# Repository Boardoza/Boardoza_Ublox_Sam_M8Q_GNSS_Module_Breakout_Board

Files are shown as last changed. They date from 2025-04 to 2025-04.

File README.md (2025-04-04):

# UBLOX SAM M8Q GNSS Module Breakout Board

The **Boardoza SAM-M8Q GNSS Breakout Module** is a **high-performance multi-GNSS receiver** designed for **precise positioning applications**. It integrates the **u-blox SAM-M8Q module**, which supports **GPS, GLONASS, and Galileo** satellite constellations for improved accuracy and reliability.  

This module operates with **3.3V or 5V**, making it compatible with a wide range of microcontrollers. It communicates with an MCU via **I<sup>2</sup>C and UART** interfaces, providing flexible integration for various applications, including **navigation systems, asset tracking, drones, and IoT-based geolocation solutions**.  

The **PPS, RST, INT, and SAFE** pins operate at **3.3V**, ensuring seamless interfacing with low-power microcontrollers.  

## [Click here to purchase!](https://www.ozdisan.com/maker-ve-iot-urunleri/boardoza/boardoza-modulleri/BOARDOZA-UBLOX/1206512)

|Front Side|Back Side|
|:---:|:---:|
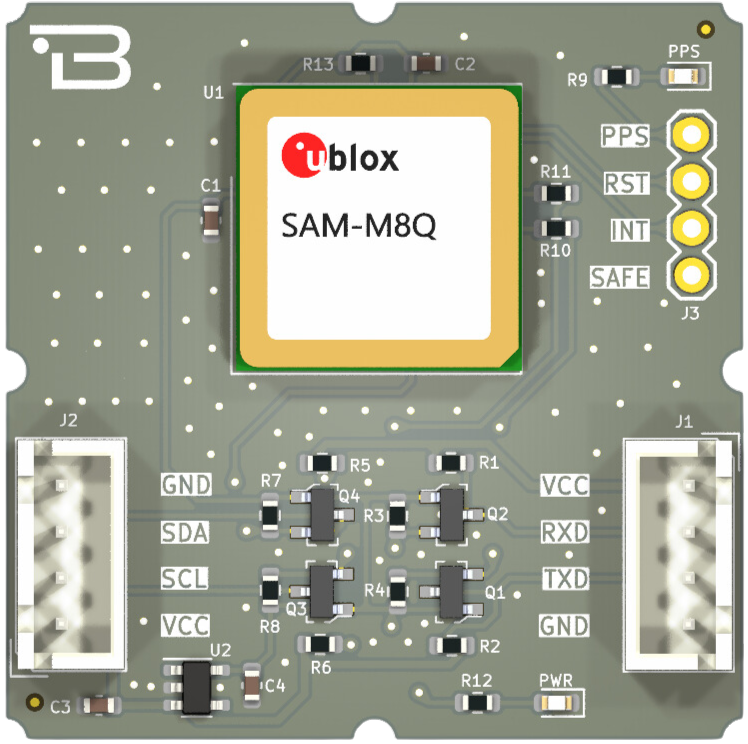
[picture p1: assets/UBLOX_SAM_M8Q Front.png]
Front
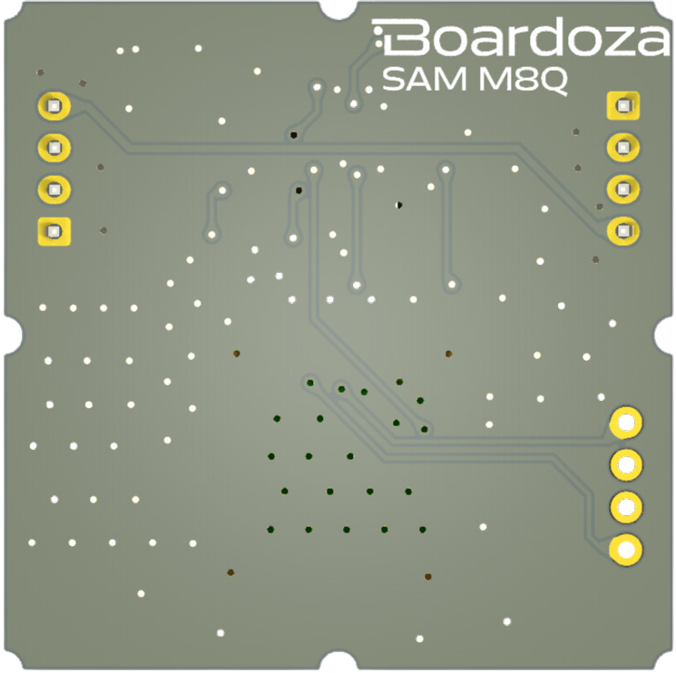
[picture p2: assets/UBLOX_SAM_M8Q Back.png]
Back
| | |

---

## Key Features

- **Multi-GNSS Support:** Compatible with GPS, GLONASS, and Galileo for enhanced positioning accuracy.  
- **Flexible Power Compatibility:** Operates with **3.3V or 5V**, making it suitable for a variety of MCUs.  
- **Dual Communication Interfaces:** Supports both **I<sup>2</sup>C and UART** for versatile connectivity.  
- **Time Pulse Output (PPS):** Provides precise timing synchronization at **1 pulse per second (default)**.  
- **Low Power Consumption:** Ideal for battery-operated applications such as **wearables and IoT tracking devices**.  
- **Industrial-Grade Performance:** Works reliably in extreme environments with a **temperature range of -40°C to +85°C**.  
- **Future-Proof Design:** Includes a **SAFEBOOT_N** function pin for firmware updates and configuration changes.  

---

## Technical Specifications

**Model:** u-blox SAM-M8Q  
**Input Voltage:** 3.3V - 5.5V  
**Voltage Input Type:** 4-pin 2.50mm header  
**Functions:** I<sup>2</sup>C and UART GNSS Receiver  
**Satellite Support:** GPS, GLONASS, Galileo, BeiDou  
**Time Pulse (PPS) Accuracy:** ±30 ns (typical)  
**Operating Temperature:** -40°C to +85°C  
**Board Dimensions:** 40mm x 40mm  

---

## Board Pinout

### **( J1 ) UART Communication Pins**  

| Pin Number | Pin Name | Description |
|:---:|:---:|---|
| 1 | GND | Ground |
| 2 | TXD | Transmitted Data Pin |
| 3 | RXD | Received Data Pin |
| 4 | VCC | Power Supply (3.3V - 5.5V) |

### **( J2 ) I<sup>2</sup>C Communication Pins**  

| Pin Number | Pin Name | Description |
|:---:|:---:|---|
| 1 | GND | Ground |
| 2 | SDA | I<sup>2</sup>C Serial Data Pin |
| 3 | SCL | I<sup>2</sup>C Serial Clock Pin |
| 4 | VCC | Power Supply (3.3V - 5.5V) |

### **( J3 ) Additional Function Pins**  

| Pin Number | Pin Name | Description |
|:---:|:---:|---|
| 1 | PPS | Time pulse signal (default: 1 pulse per second). See the u-blox M8 protocol specification for details. |
| 2 | RST | Active LOW reset pin. Internally pulled up to VCC. |
| 3 | INT | Used for time or frequency aiding data input to the receiver. |
| 4 | SAFE | SAFEBOOT_N function pin for firmware updates and reconfiguration (Reserved). |

---

## Board Dimensions

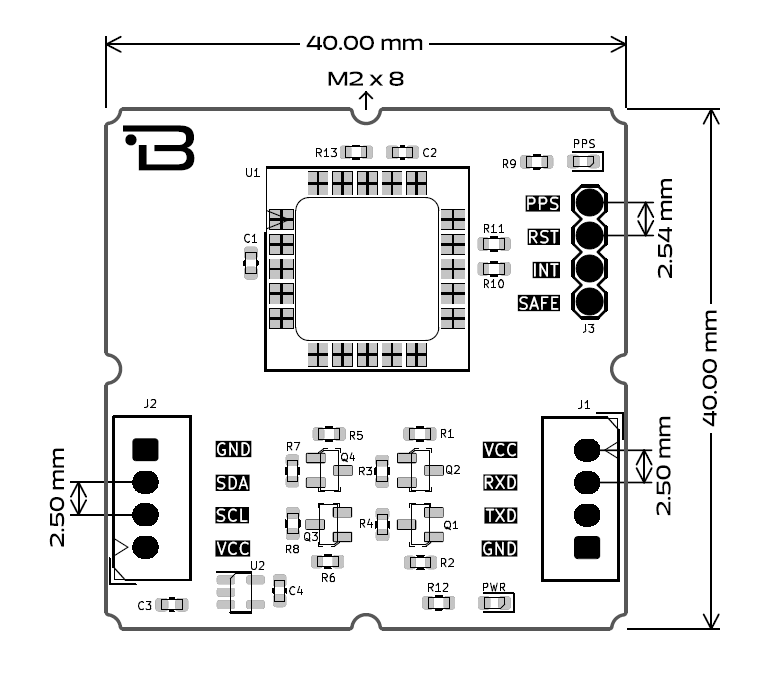
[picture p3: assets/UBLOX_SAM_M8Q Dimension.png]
Dimension


---

## Step Files

[Boardoza UBLOX SAM M8Q.step](./assets/UBLOX_SAM_M8Q%20Step.step)

---

## Datasheet

[Boardoza UBLOX SAM M8Q Datasheet.pdf](./assets/UBLOX_SAM_M8Q%20Datasheet.pdf)

---

## Version History

- V1.0.0 - Initial Release

---

## Support

- If you have any questions or need support, please contact <support@boardoza.com>

---

## License

Shield: [][cc-by-sa]

This work is licensed under a [Creative Commons Attribution-ShareAlike 4.0 International License][cc-by-sa].

[][cc-by-sa]

[cc-by-sa]: http://creativecommons.org/licenses/by-sa/4.0/
[cc-by-sa-image]: https://licensebuttons.net/l/by-sa/4.0/88x31.png
[cc-by-sa-shield]: https://img.shields.io/badge/License-CC%20BY--SA%204.0-lightgrey.svg

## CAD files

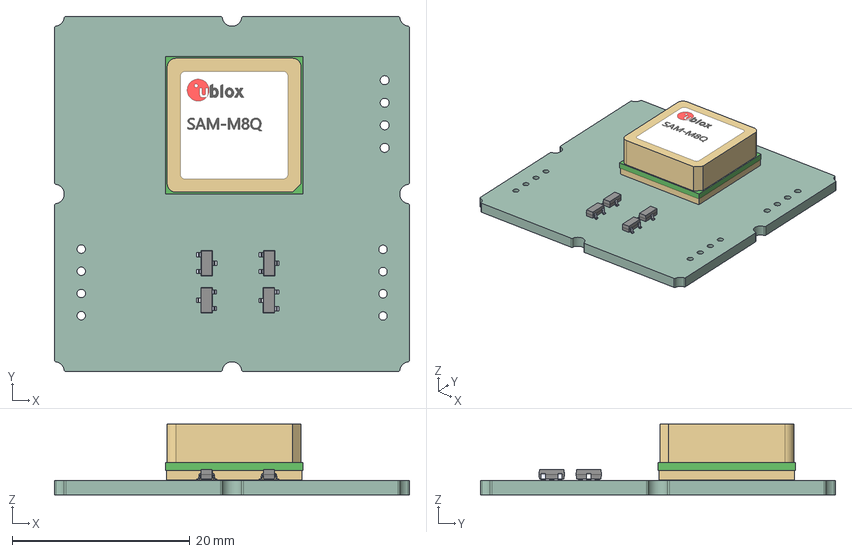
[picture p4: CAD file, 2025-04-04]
assets/UBLOX_SAM_M8Q Step.step
40.0 x 40.0 x 7.95 mm
MAX6103EUR-T x 4
sam-mq8
_autosave-B-UBLOX_SAM_M8Q-Brk-01Mbr-R01_PCB

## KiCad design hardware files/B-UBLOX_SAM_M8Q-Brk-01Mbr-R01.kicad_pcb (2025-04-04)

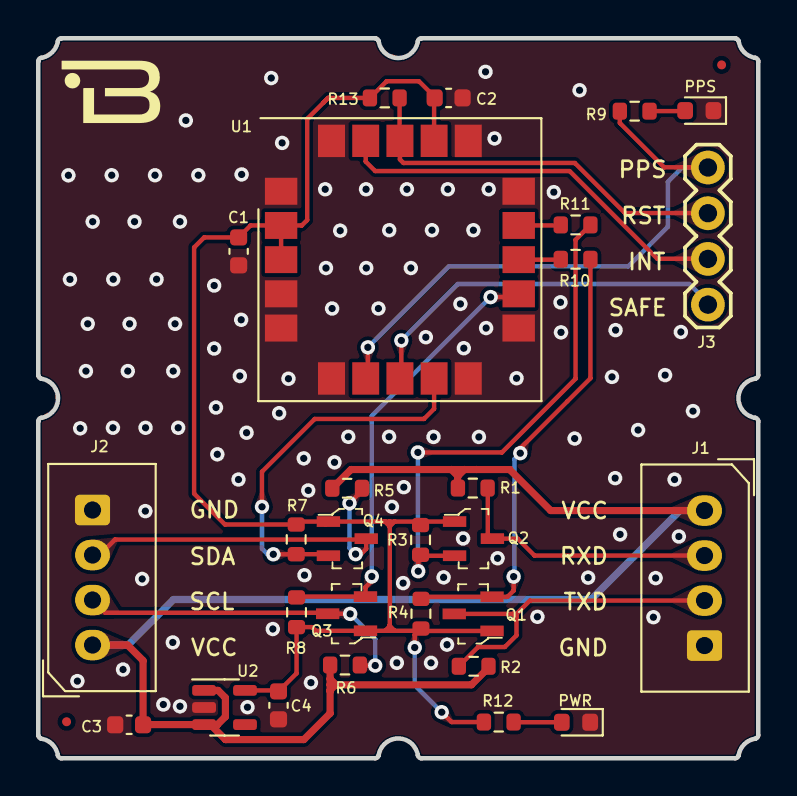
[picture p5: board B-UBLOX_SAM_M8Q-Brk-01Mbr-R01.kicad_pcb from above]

Board: 2 copper layers, 40.0 x 40.0 mm, 28 parts (0 on the bottom side), 19 nets.

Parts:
C1, C2: 100nF; C_0603_1608Metric
C3, C4: 1uF; C_0603_1608Metric
J1, J2: MOLEX_CONNECTOR_1X4; 2317-04S_1x04_P2.50mm_Vertical
J3: CONN_04; 1X04
PPS: LED RED; LED_0603_1608Metric
PWR: LED POWER; LED_0603_1608Metric
Q1, Q2, Q3, Q4: 2N7002_R1_00001; SOT-23-3
R1, R2, R3, R4, R5, R6, R7, R8, R9, R12, R13: 10K; R_0603_1608Metric
R10, R11: 470; R_0603_1608Metric
U1: ublox_SAM-M8Q
U2: TLV73333PDBVR; SOT-23-5

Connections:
+3V3: C1.1, C2.1, C4.1, Q1.1 (G), Q2.1 (G), Q3.1 (G), Q4.1 (G), R3.1, R4.1, R7.1, R8.1, R12.1, R13.2, U1.2 (VCC_IO), U1.3 (V_BCKP), U1.17 (VCC), U2.5 (OUT)
GND: C1.2, C2.2, C3.2, C4.2, J1.4, J2.4, PPS.1 (K), PWR.1 (K), U1.1 (GND), U1.4 (GND), U1.5 (GND), U1.6 (GND), U1.10 (GND), U1.11 (GND), U1.15 (GND), U1.16 (GND), U1.20 (GND), U2.2 (GND)
GPS_INT: J3.3, U1.19 (EXTINT)
GPS_RX: R11.2, U1.14 (RXD)
GPS_SCL: Q3.2 (S), R8.2, U1.12 (SCL)
GPS_SDA: Q4.2 (S), R7.2, U1.9 (SDA)
GPS_TX: R10.2, U1.13 (TXD)
unnamed: PPS.2 (A), R9.2
unnamed: PWR.2 (A), R12.2
unnamed: Q1.2 (S), R4.2, R10.1
unnamed: Q2.2 (S), R3.2, R11.1
PPS: J3.1, R9.1, U1.7 (TIMEPULSE)
RESET: J3.2, R13.1, U1.18 (~RESET)
RXD: J1.2, Q2.3 (D), R1.2
SAFEBOOT: J3.4, U1.8 (~SAFEBOOT)
SCL: J2.2, Q3.3 (D), R6.2
SDA: J2.3, Q4.3 (D), R5.2
TXD: J1.3, Q1.3 (D), R2.2
VCC: C3.1, J1.1, J2.1, R1.1, R2.1, R5.1, R6.1, U2.1 (IN), U2.3 (EN)

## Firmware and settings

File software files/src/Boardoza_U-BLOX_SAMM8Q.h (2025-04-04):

/*
  This is a library written for the u-blox ZED-F9P and NEO-M8P-2
  Boardoza sells these at its website: www.sparkfun.com
  Do you like this library? Help support SparkFun. Buy a board!
  https://www.sparkfun.com/products/16481
  https://www.sparkfun.com/products/15136
  https://www.sparkfun.com/products/15005
  https://www.sparkfun.com/products/15733
  https://www.sparkfun.com/products/15193
  https://www.sparkfun.com/products/15210

  Original version by Nathan Seidle @ SparkFun Electronics, September 6th, 2018
  v2.0 rework by Paul Clark @ SparkFun Electronics, December 31st, 2020

  This library handles configuring and handling the responses
  from a u-blox GPS module. Works with most modules from u-blox including
  the Zed-F9P, NEO-M8P-2, NEO-M9N, ZOE-M8Q, SAM-M8Q, and many others.

  https://github.com/sparkfun/SparkFun_Ublox_Arduino_Library

  Development environment specifics:
  Arduino IDE 1.8.13

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
  THE SOFTWARE IS PROVIDED "AS IS", WITHOUT WARRANTY OF ANY KIND, EXPRESS OR IMPLIED, INCLUDING BUT
  NOT LIMITED TO THE WARRANTIES OF MERCHANTABILITY, FITNESS FOR A PARTICULAR PURPOSE AND NONINFRINGEMENT.
  IN NO EVENT SHALL THE AUTHORS OR COPYRIGHT HOLDERS BE LIABLE FOR ANY CLAIM, DAMAGES OR OTHER LIABILITY,
  WHETHER IN AN ACTION OF CONTRACT, TORT OR OTHERWISE, ARISING FROM, OUT OF OR IN CONNECTION WITH THE
  SOFTWARE OR THE USE OR OTHER DEALINGS IN THE SOFTWARE.
*/

#ifndef BOARDOZA_UBLOX_SAMM8Q_H
#define BOARDOZA_UBLOX_SAMM8Q_H

#if (ARDUINO >= 100)
#include "Arduino.h"
#else
#include "WProgram.h"
#endif

#include <Wire.h>

#include <SPI.h>

#include "u-blox_config_keys.h"
#include "u-blox_structs.h"

// Uncomment the next line (or add SFE_UBLOX_REDUCED_PROG_MEM as a compiler directive) to reduce the amount of program memory used by the library
//#define SFE_UBLOX_REDUCED_PROG_MEM // Uncommenting this line will delete the minor debug messages to save memory

// Uncomment the next line (or add SFE_UBLOX_DISABLE_AUTO_NMEA as a compiler directive) to reduce the amount of program memory used by the library
//#define SFE_UBLOX_DISABLE_AUTO_NMEA // Uncommenting this line will disable auto-NMEA support to save memory

// The code exceeds the program memory on the ATmega328P (Arduino Uno), so let's delete the minor debug messages and disable auto-NMEA support anyway
// However, the ATmega2560 and ATmega1280 _do_ have enough memory, so let's exclude those
#if !defined(SFE_UBLOX_REDUCED_PROG_MEM) && defined(ARDUINO_ARCH_AVR) && !defined(ARDUINO_AVR_MEGA2560) && !defined(ARDUINO_AVR_MEGA) && !defined(ARDUINO_AVR_ADK)
#define SFE_UBLOX_REDUCED_PROG_MEM
#endif
#if !defined(SFE_UBLOX_DISABLE_AUTO_NMEA) && defined(ARDUINO_ARCH_AVR) && !defined(ARDUINO_AVR_MEGA2560) && !defined(ARDUINO_AVR_MEGA) && !defined(ARDUINO_AVR_ADK)
#define SFE_UBLOX_DISABLE_AUTO_NMEA
#endif

//-=-=-=-=-=-=-=-=-=-=-=-=-=-=-=-=-=-=-=-=-=-=-=-=-=-=-=-=-=-=-=-=-=-=-=-=

// Define a digital pin to aid debugging
// Leave set to -1 if not needed
const int debugPin = -1;

// Global Status Returns
typedef enum
{
  SFE_UBLOX_STATUS_SUCCESS,
  SFE_UBLOX_STATUS_FAIL,
  SFE_UBLOX_STATUS_CRC_FAIL,
  SFE_UBLOX_STATUS_TIMEOUT,
  SFE_UBLOX_STATUS_COMMAND_NACK, // Indicates that the command was unrecognised, invalid or that the module is too busy to respond
  SFE_UBLOX_STATUS_OUT_OF_RANGE,
  SFE_UBLOX_STATUS_INVALID_ARG,
  SFE_UBLOX_STATUS_INVALID_OPERATION,
  SFE_UBLOX_STATUS_MEM_ERR,
  SFE_UBLOX_STATUS_HW_ERR,
  SFE_UBLOX_STATUS_DATA_SENT,     // This indicates that a 'set' was successful
  SFE_UBLOX_STATUS_DATA_RECEIVED, // This indicates that a 'get' (poll) was successful
  SFE_UBLOX_STATUS_I2C_COMM_FAILURE,
  SFE_UBLOX_STATUS_DATA_OVERWRITTEN // This is an error - the data was valid but has been or _is being_ overwritten by another packet
} sfe_ublox_status_e;

// ubxPacket validity
typedef enum
{
  SFE_UBLOX_PACKET_VALIDITY_NOT_VALID,
  SFE_UBLOX_PACKET_VALIDITY_VALID,
  SFE_UBLOX_PACKET_VALIDITY_NOT_DEFINED,
  SFE_UBLOX_PACKET_NOTACKNOWLEDGED // This indicates that we received a NACK
} sfe_ublox_packet_validity_e;

// Identify which packet buffer is in use:
// packetCfg (or a custom packet), packetAck or packetBuf
// packetAuto is used to store expected "automatic" messages
typedef enum
{
  SFE_UBLOX_PACKET_PACKETCFG,
  SFE_UBLOX_PACKET_PACKETACK,
  SFE_UBLOX_PACKET_PACKETBUF,
  SFE_UBLOX_PACKET_PACKETAUTO
} sfe_ublox_packet_buffer_e;
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

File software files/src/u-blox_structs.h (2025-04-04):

/*
  This is a library written for the u-blox ZED-F9P and NEO-M8P-2
  SparkFun sells these at its website: www.sparkfun.com
  Do you like this library? Help support SparkFun. Buy a board!
  https://www.sparkfun.com/products/16481
  https://www.sparkfun.com/products/15136
  https://www.sparkfun.com/products/15005
  https://www.sparkfun.com/products/15733
  https://www.sparkfun.com/products/15193
  https://www.sparkfun.com/products/15210

  Original version by Nathan Seidle @ SparkFun Electronics, September 6th, 2018
  v2.0 rework by Paul Clark @ SparkFun Electronics, December 31st, 2020

  This library handles configuring and handling the responses
  from a u-blox GPS module. Works with most modules from u-blox including
  the Zed-F9P, NEO-M8P-2, NEO-M9N, ZOE-M8Q, SAM-M8Q, and many others.

  https://github.com/sparkfun/SparkFun_Ublox_Arduino_Library

  Development environment specifics:
  Arduino IDE 1.8.13

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
  THE SOFTWARE IS PROVIDED "AS IS", WITHOUT WARRANTY OF ANY KIND, EXPRESS OR IMPLIED, INCLUDING BUT
  NOT LIMITED TO THE WARRANTIES OF MERCHANTABILITY, FITNESS FOR A PARTICULAR PURPOSE AND NONINFRINGEMENT.
  IN NO EVENT SHALL THE AUTHORS OR COPYRIGHT HOLDERS BE LIABLE FOR ANY CLAIM, DAMAGES OR OTHER LIABILITY,
  WHETHER IN AN ACTION OF CONTRACT, TORT OR OTHERWISE, ARISING FROM, OUT OF OR IN CONNECTION WITH THE
  SOFTWARE OR THE USE OR OTHER DEALINGS IN THE SOFTWARE.
*/

#ifndef __u_blox_structs_h__
#define __u_blox_structs_h__

#include "Boardoza_U-BLOX_SAMM8Q.h"

#ifndef DEF_NUM_SENS
#define DEF_NUM_SENS 7 // The maximum number of ESF sensors
#endif

#ifndef DEF_MAX_NUM_ESF_RAW_REPEATS
#define DEF_MAX_NUM_ESF_RAW_REPEATS 10 // The NEO-M8U sends ESF RAW data in blocks / sets of ten readings. (The ZED-F9R sends them one at a time.)
#endif

#ifndef DEF_MAX_NUM_ESF_MEAS
#define DEF_MAX_NUM_ESF_MEAS 31 // numMeas is 5 bits, indicating up to 31 groups could be received
#endif

// Additional flags and pointers that need to be stored with each message type
struct ubxAutomaticFlags
{
  union
  {
    uint8_t all;
    struct
    {
      uint8_t automatic : 1;         // Will this message be delivered and parsed "automatically" (without polling)
      uint8_t implicitUpdate : 1;    // Is the update triggered by accessing stale data (=true) or by a call to checkUblox (=false)
      uint8_t addToFileBuffer : 1;   // Should the raw UBX data be added to the file buffer?
      uint8_t callbackCopyValid : 1; // Is the copy of the data struct used by the callback valid/fresh?
    } bits;
  } flags;
};

// NAV-specific structs

// UBX-NAV-POSECEF (0x01 0x01): Position solution in ECEF
const uint16_t UBX_NAV_POSECEF_LEN = 20;

typedef struct
{
  uint32_t iTOW; // GPS time of week of the navigation epoch: ms
  int32_t ecefX; // ECEF X coordinate: cm
  int32_t ecefY; // ECEF Y coordinate: cm
  int32_t ecefZ; // ECEF Z coordinate: cm
  uint32_t pAcc; // Position Accuracy Estimate: cm
} UBX_NAV_POSECEF_data_t;

typedef struct
{
  union
  {
    uint32_t all;
    struct
    {
      uint32_t all : 1;

      uint32_t iTOW : 1;
      uint32_t ecefX : 1;
      uint32_t ecefY : 1;
      uint32_t ecefZ : 1;
      uint32_t pAcc : 1;
    } bits;
  } moduleQueried;
} UBX_NAV_POSECEF_moduleQueried_t;

typedef struct
{
  ubxAutomaticFlags automaticFlags;
  UBX_NAV_POSECEF_data_t data;
  UBX_NAV_POSECEF_moduleQueried_t moduleQueried;
  void (*callbackPointer)(UBX_NAV_POSECEF_data_t);
  void (*callbackPointerPtr)(UBX_NAV_POSECEF_data_t *);
  UBX_NAV_POSECEF_data_t *callbackData;
} UBX_NAV_POSECEF_t;

// UBX-NAV-POSLLH (0x01 0x02): Geodetic position solution
const uint16_t UBX_NAV_POSLLH_LEN = 28;

typedef struct
{
  uint32_t iTOW;  // GPS time of week of the navigation epoch: ms
  int32_t lon;    // Longitude: Degrees * 1e-7
  int32_t lat;    // Latitude: Degrees * 1e-7
  int32_t height; // Height above ellipsoid: mm
  int32_t hMSL;   // Height above mean sea level: mm
  uint32_t hAcc;  // Horizontal Accuracy Estimate: mm
  uint32_t vAcc;  // Vertical Accuracy Estimate: mm
} UBX_NAV_POSLLH_data_t;

typedef struct
{
  union
  {
    uint32_t all;
    struct
    {
      uint32_t all : 1;

      uint32_t iTOW : 1;
      uint32_t lon : 1;
      uint32_t lat : 1;
      uint32_t height : 1;
      uint32_t hMSL : 1;
      uint32_t hAcc : 1;
      uint32_t vAcc : 1;
    } bits;
  } moduleQueried;
} UBX_NAV_POSLLH_moduleQueried_t;

typedef struct
{
  ubxAutomaticFlags automaticFlags;
  UBX_NAV_POSLLH_data_t data;
  UBX_NAV_POSLLH_moduleQueried_t moduleQueried;
  void (*callbackPointer)(UBX_NAV_POSLLH_data_t);
  void (*callbackPointerPtr)(UBX_NAV_POSLLH_data_t *);
  UBX_NAV_POSLLH_data_t *callbackData;
} UBX_NAV_POSLLH_t;

// UBX-NAV-STATUS (0x01 0x03): Receiver navigation status
const uint16_t UBX_NAV_STATUS_LEN = 16;
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

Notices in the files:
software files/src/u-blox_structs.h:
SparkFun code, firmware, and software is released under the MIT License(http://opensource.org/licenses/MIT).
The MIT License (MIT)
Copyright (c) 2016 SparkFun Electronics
